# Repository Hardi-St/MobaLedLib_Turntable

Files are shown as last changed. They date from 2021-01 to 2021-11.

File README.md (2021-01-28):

# MobaLedLib
## Turntable Control

### This repository contains the software and the hardware files for a Arduino based turntable control

**Features:**
- Uses a stepper motor for exact positioning
- Manual control using a poti
- Automatic control per rotation switch
- Control by command program using DCC, Selectrix or CAN
- OLED Display
- Sound generation
- Polarisation relais
- ...

**Attention:** This is the first version. Not all features are finished yet

Details could be found here:
https://stummiforum.de/viewtopic.php?t=188668

Contact: MobaLedLib@gmx.de

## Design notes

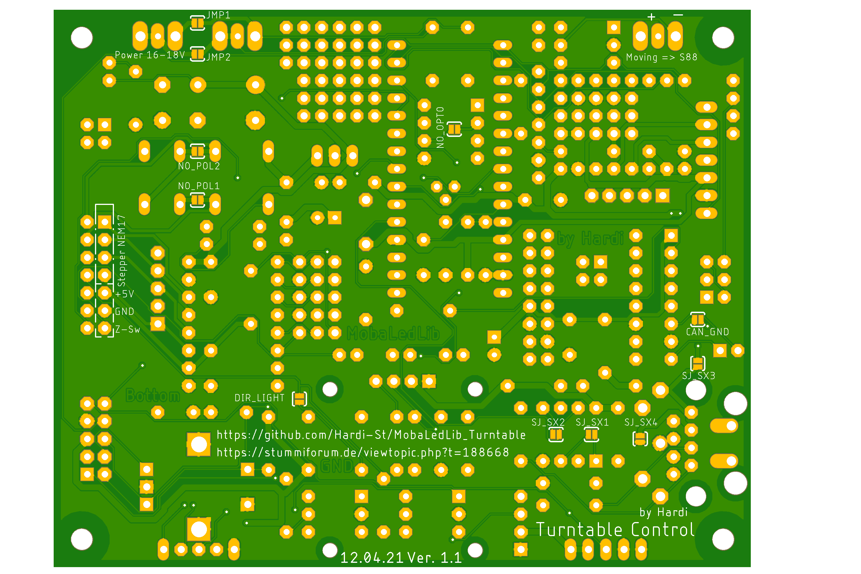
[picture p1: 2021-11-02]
brd/Turntable_Bot.png

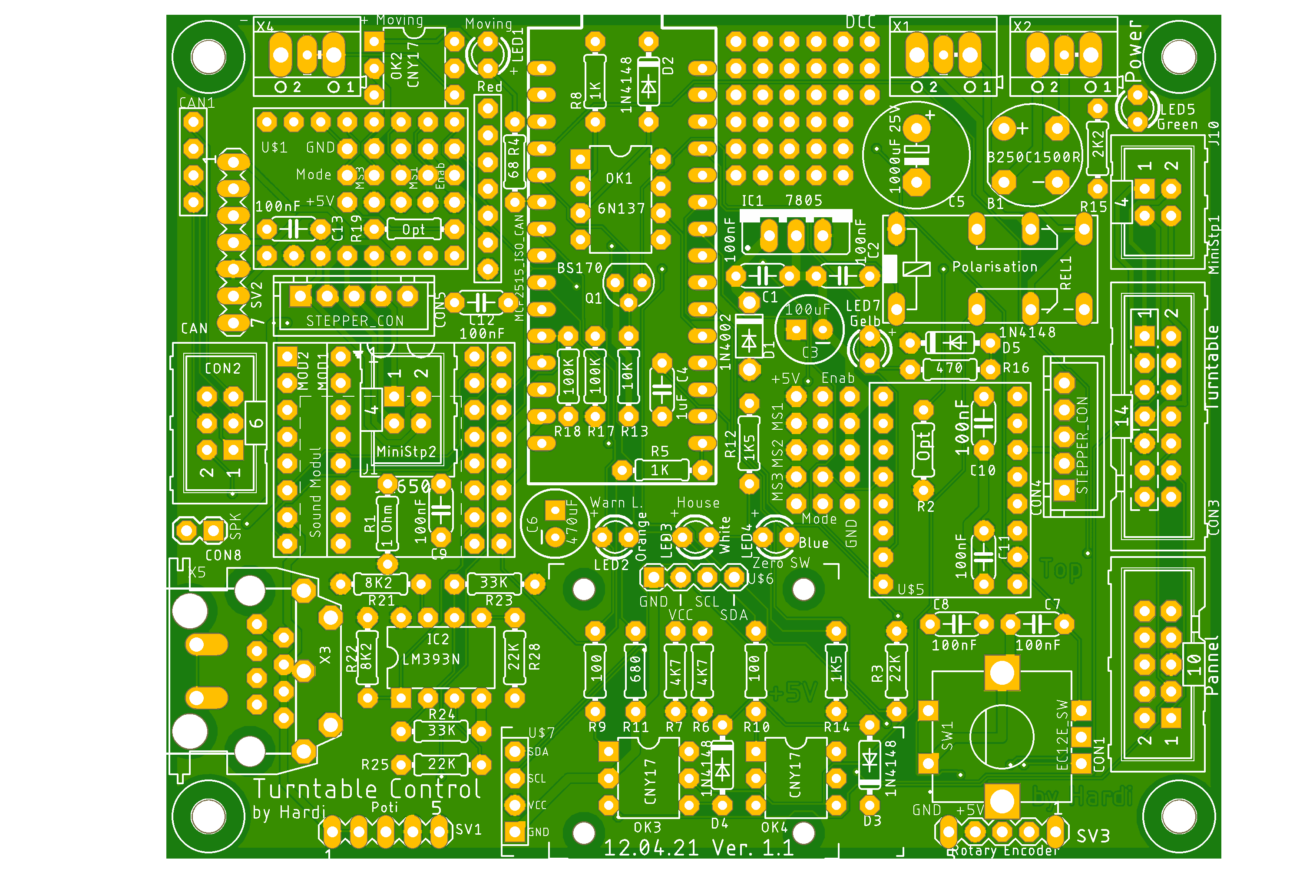
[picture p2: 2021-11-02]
brd/Turntable_Top.png

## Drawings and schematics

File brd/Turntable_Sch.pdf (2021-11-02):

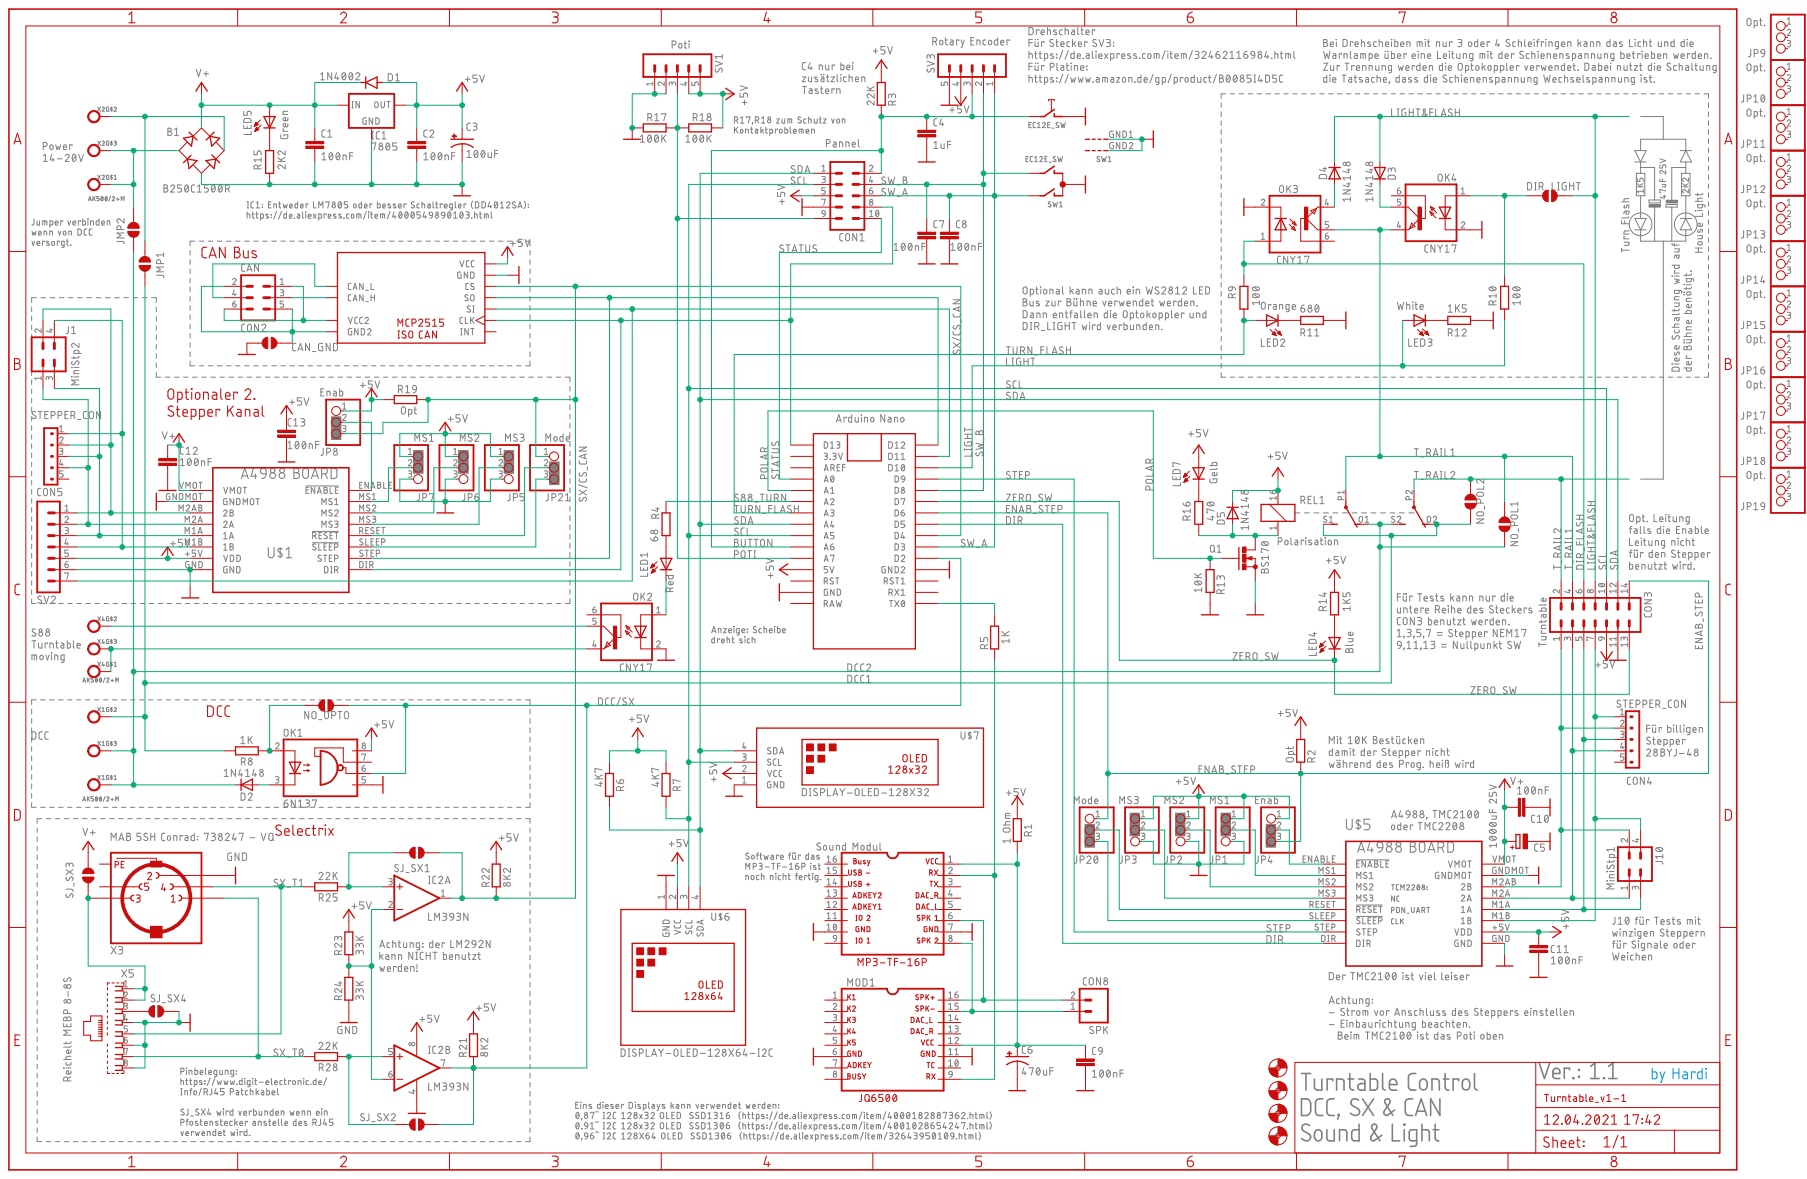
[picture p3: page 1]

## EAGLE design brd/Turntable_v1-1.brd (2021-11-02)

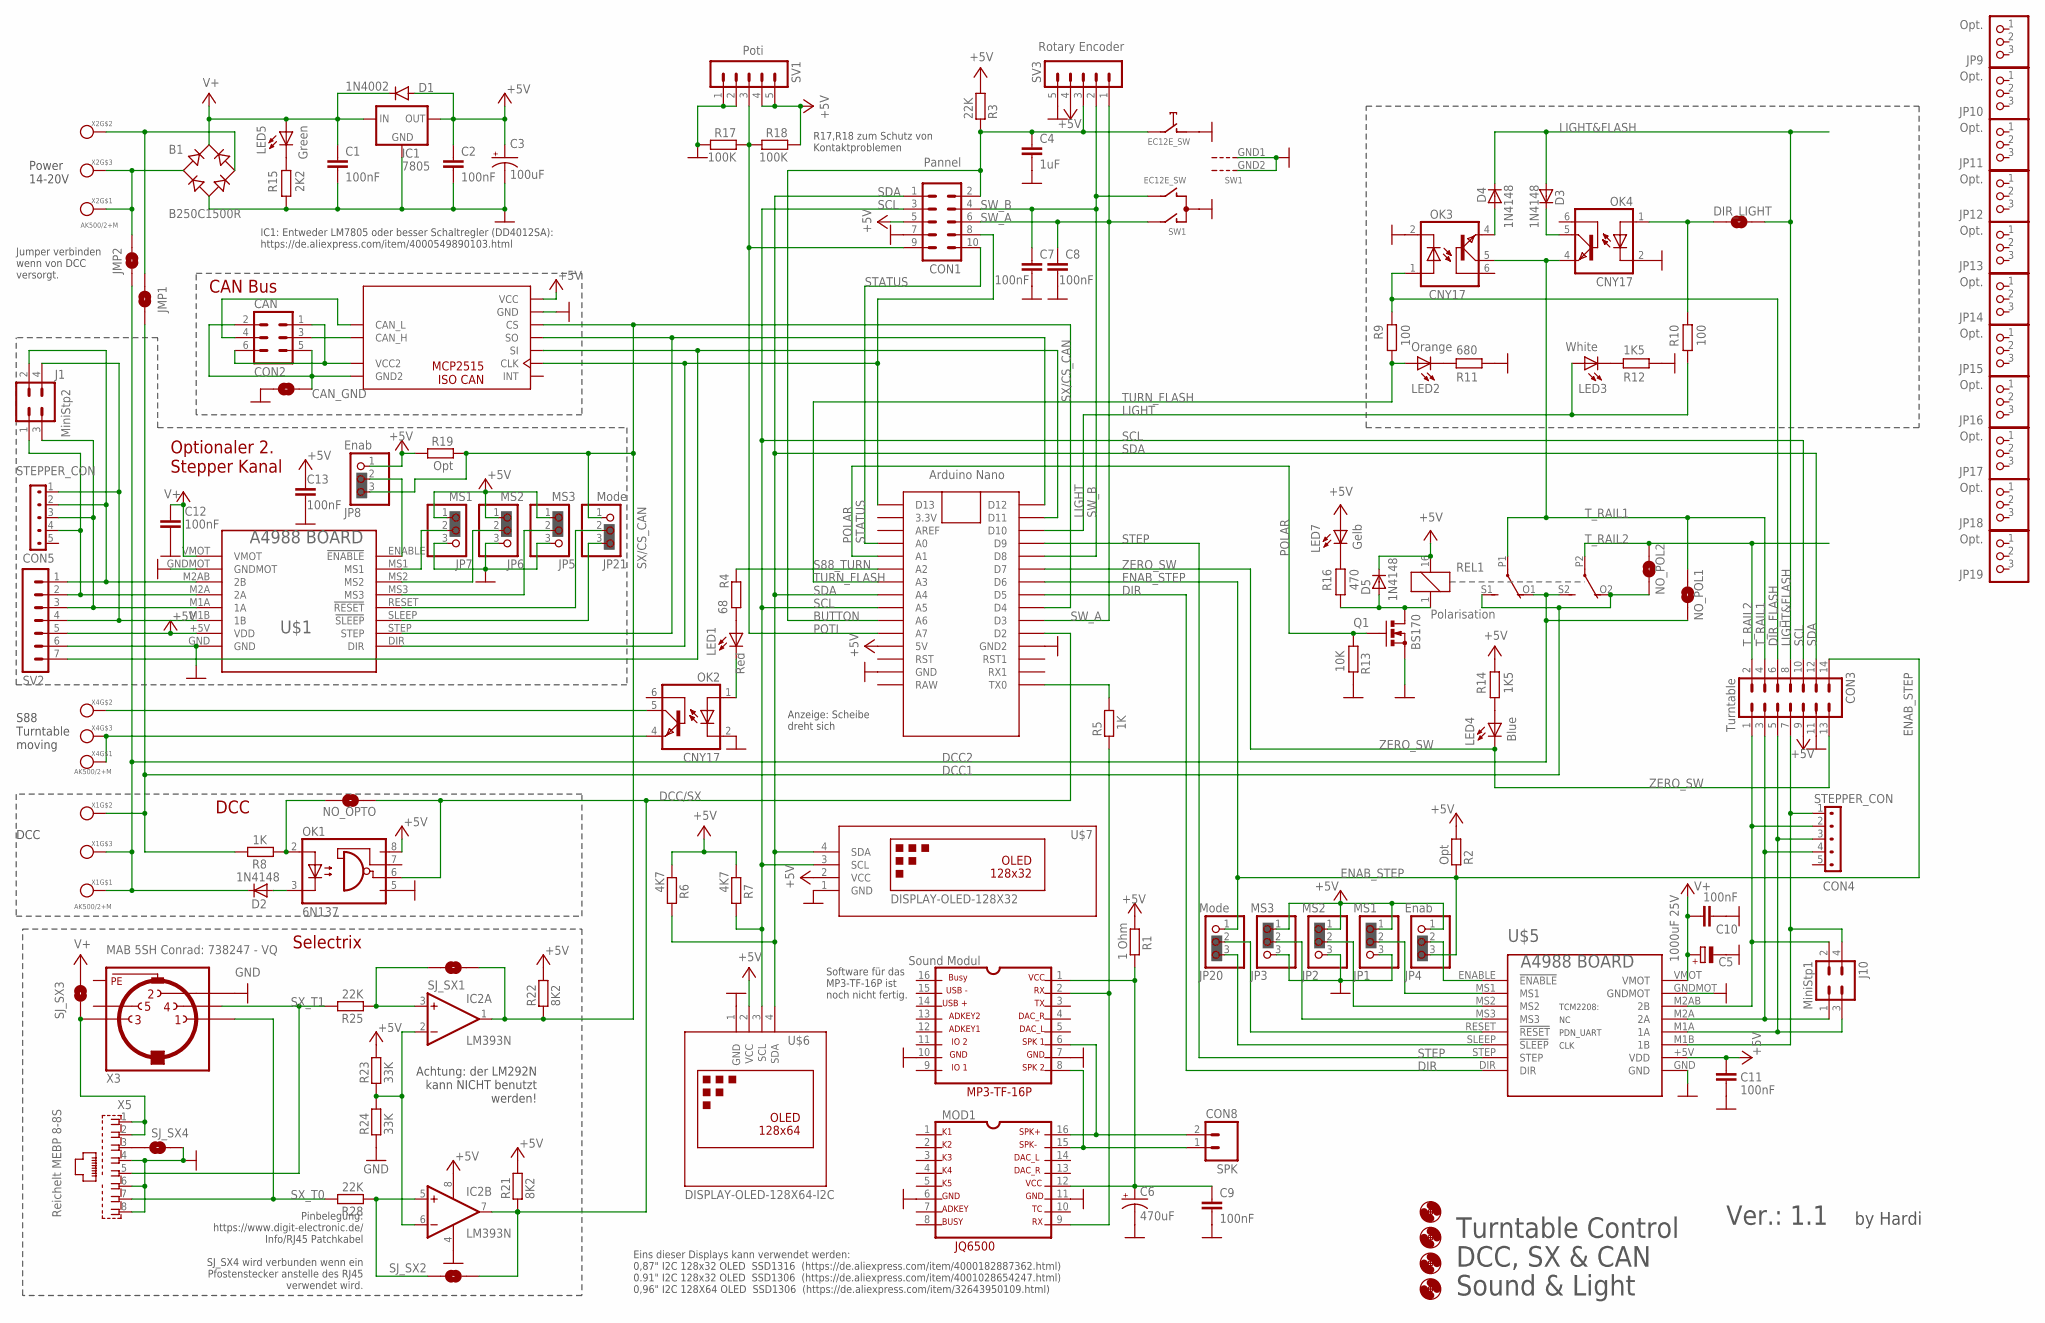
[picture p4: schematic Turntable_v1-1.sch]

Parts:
B1: B250C1500R; RB1A
C1, C2, C7, C8, C9, C10, C11, C12, C13: 100nF; C050-024X044
C3: 100uF; SPARKFUN-CAPACITORS_CPOL-RADIAL-100UF-25V
C4: 1uF; C050-024X044
C5: 1000uF 25V; E5-10,5
C6: 470uF; SPARKFUN-CAPACITORS_CPOL-RADIAL-100UF-25V
CAN1: MCP2515_ISO_CAN
CAN_GND: SOLDERJUMPERNO; SJ_2S-NO
CON1: Pannel; ML10
CON2: CAN; ML6
CON3: Turntable; ML14
CON4, CON5: STEPPER_CON
CON8: SPK; 1X02
D1: 1N4002; DO41-10
D2, D3, D4, D5: 1N4148; DO35-7
DIR_LIGHT: SOLDERJUMPERNO; SJ_2S-NO
H1, H2, H3, H4: MOUNT-HOLE3.0; 3,0
IC1: 7805; 78XXS
IC2: LM393N; DIL08
J1: MiniStp2; CON-HARTING-ML_ML4
J10: MiniStp1; CON-HARTING-ML_ML4
JMP1, JMP2: SOLDERJUMPERNO; SJ_2S-NO
JP1, JP7: MS1; 1X03-CLEANBIG
JP2, JP6: MS2; 1X03-CLEANBIG
JP3, JP5: MS3; 1X03-CLEANBIG
JP4, JP8: Enab; 1X03-CLEANBIG
JP9, JP10, JP11, JP12, JP13, JP14, JP15, JP16, JP17, JP18, JP19: Opt.; 1X03-CLEANBIG
JP20, JP21: Mode; 1X03-CLEANBIG
LED1: Red; LED3MM
LED2: Orange; LED3MM
LED3: White; LED3MM
LED4: Blue; LED3MM
LED5: Green; LED3MM
LED7: Gelb; LED3MM
MOD1: JQ6500
MOD2: Sound Modul; MP3-TF-16P_MP3-TF-16P
NO_OPTO: SOLDERJUMPERNO; SJ_2S-NO
NO_POL1, NO_POL2: SOLDERJUMPERNO; SJ_2S-NO
OK1: 6N137; DIL08
OK2, OK3, OK4: CNY17; DIL06
Q1: BS170; SOT54E
R1: 1 Ohm; RCL_0204/7
R2, R19: Opt; 0204/7
R3, R25, R28: 22K; 0204/7
R4: 68; 0204/7
R5, R8: 1K; 0204/7
R6, R7: 4K7; RCL_0204/7
R9, R10: 100; 0204/7
R11: 680; 0204/7
R12, R14: 1K5; 0204/7
R13: 10K; 0204/7
R15: 2K2; 0204/7
R16: 470; 0204/7
R17, R18: 100K; 0204/7
R21, R22: 8K2; 0204/7
R23, R24: 33K; 0204/7
REL1: Polarisation; 351
SJ_SX1, SJ_SX2, SJ_SX3, SJ_SX4: SOLDERJUMPERNO; SJ_2S-NO
SV1: Poti; MA05-1
SV2: MA07-1
SV3: Rotary Encoder; MA05-1_SMALL_PAD
SW1: EC12E_SW; ALPS_EC12E_SW
U2: LED NANO; NANO
U$1, U$5: BOARD_A4988
U$6: DISPLAY-OLED-128X64-I2C
U$7: DISPLAY-OLED-128X32
X1, X2, X4: AK500/2+M
X3: MAB 5SH Conrad: 738247 - VQ; MAB5SH
X5: Reichelt MEBP 8-8S; RJ45_MEBP8-8S

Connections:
+5V: C2.1, C3.1 (+), C11.1, C13.1, CAN1.1 (VCC), CON1.5, CON3.9, D1.A, D5.C, IC1.OUT, IC2.8 (V+), JP1.1, JP2.1, JP3.1, JP4.1, JP5.1, JP6.1, JP7.1, JP8.1, LED7.A, OK1.8 (VCC), R1.1, R2.2, R3.2, R6.1, R7.1, R14.1, R18.1, R19.2, R21.2, R22.2, R23.2, REL1.16 (2), SV1.4, SV1.5, SV2.5, SV3.4, U2.5V, U$1.+5V (VDD), U$5.+5V (VDD), U$6.2 (VCC), U$7.2 (VCC)
BUTTON: C4.1, CON1.2, R3.1, SV3.3, SW1.E (2), U2.A6
CAN_H: CAN1.9 (CAN_H), CON2.3
CAN_L: CAN1.8 (CAN_L), CON2.4
D11: CAN1.5 (SI), SV2.7, U2.D11
D12: CAN1.4 (SO), U2.D12, U$1.STEP
DCC1: JMP1.2, NO_POL2.2, R8.2, REL1.O2 (O), REL1.S1 (S), X1.2
DCC2: D2.C, JMP2.2, NO_POL1.2, REL1.O1 (O), REL1.S2 (S), X1.1, X1.M
DCC/SX: IC2.7 (OUT), NO_OPTO.1, OK1.6 (VO), R21.1, SJ_SX2.2, U2.D2
DIR: U2.D5, U$5.DIR
DIR_FLASH: CON3.6, OK3.1 (A), R9.1
ENAB_STEP: CON3.14, JP4.3, JP20.1, R2.1, U2.D6
GND: B1.-, C1.2, C2.2, C3.2 (-), C4.2, C5.-, C6.2 (-), C7.2, C8.2, C9.2, C10.2, C11.2, C12.2, C13.2, CAN1.2 (GND), CAN_GND.2, CON1.7, CON3.11, IC1.GND, IC2.4 (V-), JP1.3, JP2.3, JP3.3, JP5.3, JP6.3, JP7.3, MOD1.6, MOD1.11, MOD2.7, MOD2.10, OK1.5 (GND), OK2.2 (C), OK3.2 (C), OK4.2 (C), Q1.S, R11.2, R12.2, R13.2, R15.2, R17.2, R24.1, SJ_SX4.2, SV1.1, SV1.2, SV2.6, SV3.5, SW1.C, SW1.D (1), SW1.GND1 (G), SW1.GND2 (G), U2.GND, U2.GND1 (GND2), U$1.GND, U$1.GNDMOT, U$5.GND, U$5.GNDMOT, U$6.1 (GND), U$7.1 (GND), X3.2, X5.4, X5.6, X5.8
LIGHT: LED3.A, R10.2, U2.D10
LIGHT&FLASH: CON3.8, D3.A, D4.C, DIR_LIGHT.2
unnamed: JP5.2, U$1.MS3
unnamed: SJ_SX4.1, X5.3
unnamed: CAN1.11 (GND2), CAN_GND.1, CON2.2, CON2.5
unnamed: C6.1 (+), C9.1, MOD1.12, MOD2.1, R1.2
unnamed: CAN1.6 (CLK), CON1.8, U2.D13, U$1.DIR
unnamed: CON8.1, MOD1.15, MOD2.8
unnamed: MOD1.9, MOD2.2, R5.1
unnamed: LED1.K (C), OK2.1 (A)
unnamed: CON8.2, MOD1.16, MOD2.6
unnamed: CAN1.10 (VCC2), CON2.1, CON2.6
unnamed: R5.2, U2.TX0
unnamed: B1.AC2, JMP1.1, X2.2
unnamed: B1.AC1, JMP2.1, X2.1, X2.M
unnamed: JP2.2, U$5.MS2
unnamed: D2.A, OK1.3 (C)
unnamed: LED2.K (C), R11.1
unnamed: D5.A, Q1.D, R16.2, REL1.1
unnamed: LED1.A, R4.1
unnamed: OK2.4 (EMI), X4.1, X4.M
unnamed: OK2.5 (COL), X4.2
unnamed: NO_OPTO.2, OK1.2 (A), R8.1
unnamed: JP1.2, U$5.MS1
unnamed: LED3.K (C), R12.1
unnamed: LED4.A, R14.2
unnamed: JP4.2, U$5.ENABLE (!ENABLE)
unnamed: SJ_SX3.1, X3.3, X5.1, X5.2
unnamed: JP3.2, U$5.MS3
unnamed: D4.A, OK3.4 (EMI)
unnamed: D3.C, OK4.5 (COL)
unnamed: JP20.2, U$5.RESET (!RESET)
unnamed: CON3.1, CON4.2, J10.2, U$5.M2AB (2B)
unnamed: JP21.3, U$1.SLEEP (!SLEEP)
unnamed: JP20.3, U$5.SLEEP (!SLEEP)
unnamed: LED5.K (C), R15.1
unnamed: CON3.7, CON4.1, J10.4, U$5.M1B (1B)
unnamed: LED7.K (C), R16.1
unnamed: DIR_LIGHT.1, OK4.1 (A), R10.1
unnamed: IC2.2 (-IN), IC2.6 (-IN), R23.1, R24.2
unnamed: IC2.3 (+IN), R25.1, SJ_SX1.1
unnamed: CON3.3, CON4.4, J10.1, U$5.M2A (2A)
unnamed: CON3.5, CON4.3, J10.3, U$5.M1A (1A)
unnamed: IC2.5 (+IN), R28.1, SJ_SX2.1
unnamed: JP6.2, U$1.MS2
unnamed: JP7.2, U$1.MS1
unnamed: JP8.2, U$1.ENABLE (!ENABLE)
unnamed: JP21.2, U$1.RESET (!RESET)
unnamed: CON5.2, J1.2, SV2.1, U$1.M2AB (2B)
unnamed: CON5.4, J1.1, SV2.2, U$1.M2A (2A)
unnamed: CON5.3, J1.3, SV2.3, U$1.M1A (1A)
unnamed: CON5.1, J1.4, SV2.4, U$1.M1B (1B)
PE: X3.PE, X3.PE@ (PE)
POLAR: Q1.G, R13.1, U2.A1
POTI: CON1.9, R17.1, R18.2, SV1.3, U2.A7
S88_TURN: R4.2, U2.A2
SCL: CON1.3, CON3.10, R7.2, U2.A5, U$6.3 (SCL), U$7.3 (SCL)
SDA: CON1.1, CON3.12, R6.2, U2.A4, U$6.4 (SDA), U$7.4 (SDA)
STATUS: CON1.10, U2.A0
STEP: U2.D9, U$5.STEP
SW_A: C8.1, CON1.6, SV3.1, SW1.A, U2.D3
SW_B: C7.1, CON1.4, SV3.2, SW1.B, U2.D8
SX/CS_CAN: CAN1.3 (CS), IC2.1 (OUT), JP8.3, JP21.1, R19.1, R22.1, SJ_SX1.2, U2.D4
SX_T0: R28.2, X3.1, X5.7
SX_T1: R25.2, X3.4, X5.5
TURN_FLASH: LED2.A, R9.2, U2.A3
T_RAIL1: CON3.4, NO_POL1.1, OK3.5 (COL), OK4.4 (EMI), REL1.P1
T_RAIL2: CON3.2, NO_POL2.1, REL1.P2
V+: B1.+, C1.1, C5.+, C10.1, C12.1, D1.C, IC1.IN, LED5.A, SJ_SX3.2, U$1.VMOT, U$5.VMOT
ZERO_SW: CON3.13, LED4.K (C), U2.D7

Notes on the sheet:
Pinbelegung: https://www.digit-electronic.de/ Info/RJ45 Patchkabel SJ_SX4 wird verbunden wenn ein Pfostenstecker anstelle des RJ45 verwendet wird.
Achtung: der LM292N kann NICHT benutzt werden!
DCC
IC1: Entweder LM7805 oder besser Schaltregler (DD4012SA): https://de.aliexpress.com/item/4000549890103.html
by Hardi
Ver.: 1.1
Turntable Control DCC, SX & CAN Sound & Light
S88 Turntable moving
Power 14-20V
R17,R18 zum Schutz von Kontaktproblemen
Optionaler 2. Stepper Kanal
Jumper verbinden wenn von DCC versorgt.
Anzeige: Scheibe dreht sich
Software für das MP3-TF-16P ist noch nicht fertig.
DCC
CAN Bus
Selectrix
Eins dieser Displays kann verwendet werden: 0,87" I2C 128x32 OLED SSD1316 (https://de.aliexpress.com/item/4000182887362.html) 0.91" I2C 128x32 OLED SSD1306 (https://de.aliexpress.com/item/4001028654247.html) 0,96" I2C 128X64 OLED SSD1306 (https://de.aliexpress.com/item/32643950109.html)
TCM2208: NC PDN_UART CLK

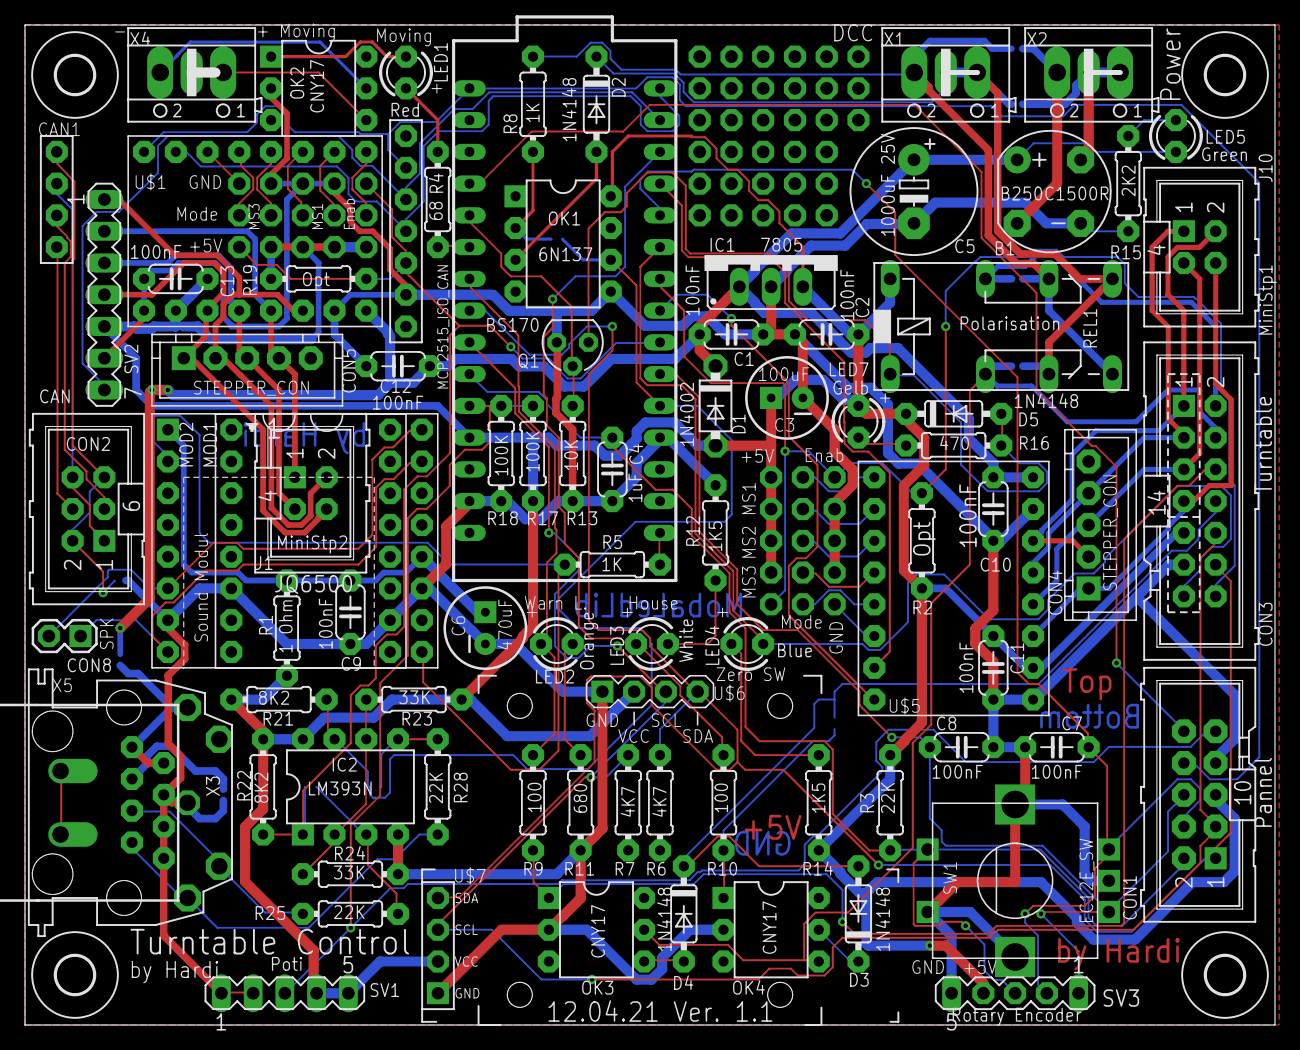
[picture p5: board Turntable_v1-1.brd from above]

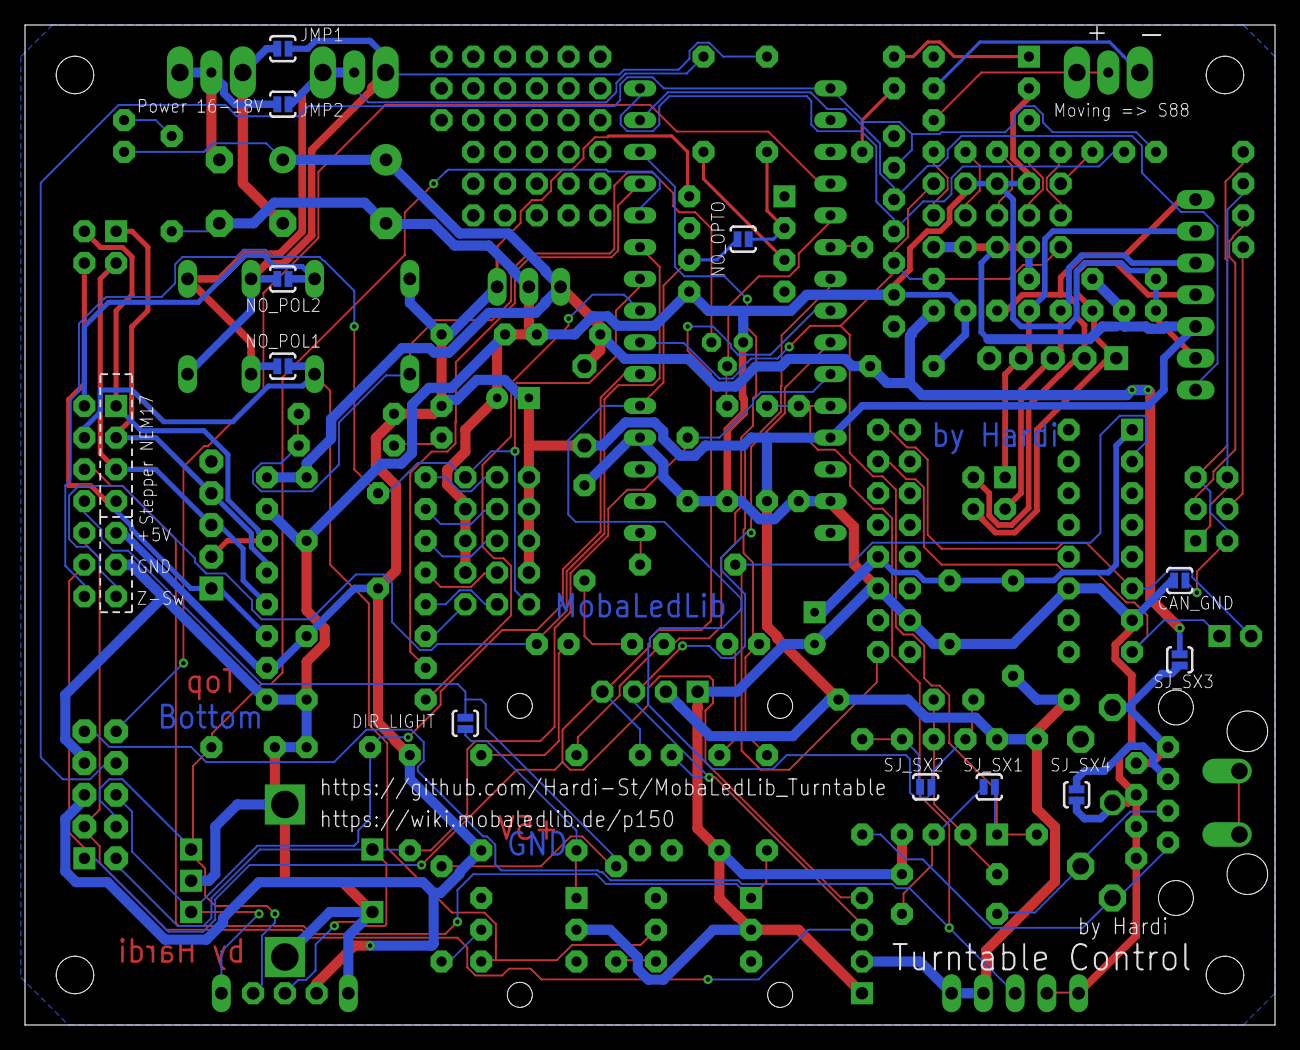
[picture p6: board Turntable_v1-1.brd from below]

Board: 2 copper layers, 100.0 x 80.0 mm, 119 parts (11 on the bottom side), 83 nets.

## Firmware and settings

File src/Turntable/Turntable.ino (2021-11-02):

/*
 The idea to create a own inexpensive hard and software for a turntable was generated by this post from Frank:
   https://www.stummiforum.de/viewtopic.php?t=140471&start=401&sd=a

 He uses the 3D printed turntabele from
   https://www.thingiverse.com/thing:1837520
31083 30916 167

 Revision History:
 ~~~~~~~~~~~~~~~~~
 13.12.20:  - Setting zero position if more than one turn is detected in both directions
            - Fast move to contact point with poti
 15.12.20:  - Current for stepper (28BYJ-48) incremented 0.17V = 300mA to prevent
              loosing steps (Old: 0.14V = 200mA)
 21.12.20:  - Actual Current settings 0.24V (Changed back to 0.14 later because the stepper gets to hot)
 26.12.20:  - Reading the actual port from the step position if moved by poti
            - Using a quadratic function to define the speed for a finer positioning
            - Reading the Port_Pos[] directly from the EEPROM to save RAM
            - Use FastPin instead of digitalWrite function to save memory and speed op the program
 27.12.20:  - Added the rotation switch menu
 28.12.20:  - Saving the position to the EEPROM to avoid callibration at startup
            - Port numbers shown to the user start with 1 and not with 0
            - Corrected Get_Next_Port_from_Actual_Position() to be able to use negativ Port_Pos[] entries
            - Detect if the poti is not 0 at the beginning
 29.12.20:  - Added the polarisation relais function
 02.01.21:  - Support for the u8x8 display mode which saves 10% Flash and doesn't need RAM for the display buffer
            - Option to use a second lagrer font for the numbers
 03.01.21:  - Reset uses the Jump 0 command because the watchdog reset doesn't work when an old bootloader is used
            - Polarisation relais could be configured individuel for each port
 05.01.21:  - Added several functions to controll the turntable with DCC
            - Prevent overwriting the EEPROM by the NmraDcc library
            - Support for 0.96" OLED display with 128x64 pixel
            - Pin which indicates that the turntable is moving to conect a S88 modul.
 07.01.21:  - Added the ability to change the rotation / port number direction of the turntable "TURNTABLE_DIRECTION"
            - Port number could be selected in the "Save position" menu only once at the beginning to
              prevent wrong sequences. Call "Reset all" to change the sequence.
            - Moved the poti to A7 because A0 could also be used as output. This could be changed with:
                #define POTI_PIN A0
            - Moved the rotation switch button to A6. This could be changed with:
                #define ENCODER_SW_PIN 9
              to the old pin number in the config file
            - Light which flashes while the turntable moves
            - Added the "avdweb_AnalogReadFast.h library to read speed up the analog reading
            - Diagnose display to check the analog values
            - Activating a sound modul if the turntable starts/stops moving
            - Additional DCC functions for Sound and Light
 08.01.21:  - Last menu position is stored. By default the "Reverse" line is activated
              => A double click could be used to reverse the turntable.
              This is also useful to save the port positions...
            - Stopping fast if the poti is turned to 0. Prior the time depends on the last speed.
            - Added MOVING_FLASH_INVERS
            - Filling also the port positions of the oposite direction with standard values when the first
              port in oposite direction is defined
 09.01.21:  - Storing Act_Port to the EEPROM
            - New handling of the reverse command. The start port is stored to Rev_Port to be able to
              rotate back again. The display shoa the reverse port in a second line.
            - Soved problem with Port < 24 at two positions
              - caused the wrong turn direction at Port 0 when tuned the rotation key back to 24
              - storing the Act_Port in Reverse_TurnTable
            - Checked with the maximal PORT_CNT of 80.
            - Corrected Get_Next_Port_from_Actual_Position(). Problem if one port is left, the other right of 0
            - Zero position is always set in positive direction
              Could be disabled with #define ALWAYS_SET_ZERO_IN_POS_DIR  0
              Prior it was only set after one turn.
            - Reversing the turntable if the same port command is received twice.
              Could be disabeld with #define REVERSE_IF_SAME_PORT_IS_RECEIVED 0
              If it's disabled the sound is not played.
 10.01.21:  - Storing the reverse positions to the EEPROM to be able to adjust them individually
            - Replaced the "Move_to_Port_or_Pos()" Function by two separate functions:
              "Move_to_Port()" and "Move_to_StepPos()" because the old function used the value of the parameter
              to detect if it was ment as Port or StepPos (Abs(x) < 2*PORT_CNT). This was fine for manual
              tests, but can't be used in an automatic mode where a StepPos could also be < PORT_CNT.
 11.01.21:  - Disabled the flickering of the display if USE_u8x8 is used
            - New menu option "Move manual"
            - Improved the decoding of the rotation switch
            - Corrected playing sound at the beginning of the movement
 12.01.21:  - Using the serial port to play the sounds
              - Number of sounds could be lager. At the moment 8 files could be used with DCC
              - Is connected to the serial port => No other pin needed
              - Debug outputs must use 9600 Baud ;-( but debuging is still possible in paralel
              - DCC Functions added to change the volume
            - Don't reverse per DCC while moving
 17.01.21:  => Send to Han
            - Moving to contact before moving to a port. This caused a lot of changes.
            - Delayed start moving if DELAY_TURN_START_SOUND is given
 23.01.21:  - Added Menu Sound
 10.02.21:  - Added 1.3" OLED Display
            - I2C speed set tor 400kHz
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

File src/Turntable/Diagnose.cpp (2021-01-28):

/*
 Diagnose functions for the turntable
 ~~~~~~~~~~~~~~~~~~~~~~~~~~~~~~~~~~~~
 - Check lost stepps
   - At constant speed
   - When acceleration deceleration is used
*/

#include <Arduino.h>
#include <MobaTools.h>  // https://github.com/MicroBahner/MobaTools

#include "Turntable_Config.h"       // Local configuration file. The file could be empty. In this case the default values are used (See below).
#include "Diagnose.h"

#ifndef ENABLE_DIAGNOSE
#define ENABLE_DIAGNOSE              0
#endif

#ifndef DIAG_CONST_SPEED_START_SPEED
#define DIAG_CONST_SPEED_START_SPEED 25000
#endif

#ifndef DIAG_CONST_SPEED_END_SPEED
#define DIAG_CONST_SPEED_END_SPEED   10000
#endif

#ifndef DIAG_CONST_SPEED_SPEED_STEPP
#define DIAG_CONST_SPEED_SPEED_STEPP -1000
#endif

#ifndef DIAG_CONST_SPEED_N_TESTS
#define DIAG_CONST_SPEED_N_TESTS     5
#endif

//#ifndef DIAG_PAUSE_BETWEEN_TESTS
//#define DIAG_PAUSE_BETWEEN_TESTS     0   // [s]
//#endif

#ifndef DIAG_START_OFFSET
#define DIAG_START_OFFSET            3000
#endif





extern class MoToStepper Step1;

bool Get_Zero_SW();
void WaitforZeroSwitch(bool val);
long WaitforZeroSwitch_readSteps_Debounce(bool val);
void WaitforZeroSwitch_and_SetZero();
void WaitUntilStopped(bool DisableA4988);

//----------------------------------------------
long Check_Steps_for_one_Turn(uint16_t CalSpeed)
//----------------------------------------------
{
  long StepsOneTurn;
  Step1.rotate(1);
  Step1.setSpeedSteps(CalSpeed);

  if (Get_Zero_SW())                          // If the zero switch is achtive => Move until it's released
     WaitforZeroSwitch_readSteps_Debounce(0); // Wait until the zero switch is released

  // *** Set the zero position ***
  //DprintlnT("Searching the zero position...");
  WaitforZeroSwitch_and_SetZero();

  // *** Get the total number of steps ***
  WaitforZeroSwitch_readSteps_Debounce(1);    // Debouncing
  WaitforZeroSwitch_readSteps_Debounce(0);    // Wait until the switch is 0
  //DprintlnT("Rotate one turn to get the total number of steps");

  WaitforZeroSwitch(1);                       // Rotate one turn until the switch is active again
  StepsOneTurn = Step1.readSteps();
  Step1.setZero();
  Serial.print(F("Speed: ")); Serial.print(CalSpeed); Serial.print(F(" StepsOneTurn: ")); Serial.println(StepsOneTurn);
  Step1.doSteps((long)-DIAG_START_OFFSET); // Move back (To start at the same position)
  WaitUntilStopped(false);
  return StepsOneTurn;
}

//-----------------------------------------------------------------
void Check_Steps_for_one_Turn_N_times(uint16_t CalSpeed, uint8_t n)
//-----------------------------------------------------------------
{
 long StepsOneTurn_Sum = 0;
 long MaxVal = 0;
 long MinVal = 0x7FFFFFFF;
 for (uint8_t i = 0; i < n; i++)
    {
    long StepsOneTurn = Check_Steps_for_one_Turn(CalSpeed);
    StepsOneTurn_Sum += StepsOneTurn;
    if (StepsOneTurn > MaxVal) MaxVal = StepsOneTurn;
    if (StepsOneTurn < MinVal) MinVal = StepsOneTurn;
    }
 Serial.print(F(". . . .\t\t\t\t\t\t\tAvg: ")); Serial.print(StepsOneTurn_Sum/n); Serial.print(F(" MaxDif: ")); Serial.println(MaxVal - MinVal);
}

//----------------------------------
void Check_Steps_at_Constant_Speed()
//----------------------------------
// Check the number of steps for one turn at different but constant speeds
{
  uint16_t CalSpeed = DIAG_CONST_SPEED_START_SPEED;
  do {
     Check_Steps_for_one_Turn_N_times(CalSpeed, DIAG_CONST_SPEED_N_TESTS);
     CalSpeed += DIAG_CONST_SPEED_SPEED_STEPP;
     } while((DIAG_CONST_SPEED_SPEED_STEPP > 0 && CalSpeed <= DIAG_CONST_SPEED_END_SPEED) ||
             (DIAG_CONST_SPEED_SPEED_STEPP < 0 && CalSpeed >= DIAG_CONST_SPEED_END_SPEED));
}
/*

Lego "Stepper" ohne Getriebe und ohne Reibung, A4988, MS1-3 +5v, 0.2A, 0.152V, 14V, A4988
Speed: 5000 StepsOneTurn: 32752
Speed: 5000 StepsOneTurn: 32762
Speed: 5000 StepsOneTurn: 32764
Speed: 5000 StepsOneTurn: 32771
Speed: 5000 StepsOneTurn: 32769
. . . .                         Avg: 32763 MaxDif: 19
Speed: 6000 StepsOneTurn: 32767
Speed: 6000 StepsOneTurn: 32763
Speed: 6000 StepsOneTurn: 32768
Speed: 6000 StepsOneTurn: 32769
Speed: 6000 StepsOneTurn: 32768
. . . .                         Avg: 32767 MaxDif: 6
Speed: 7000 StepsOneTurn: 32765
Speed: 7000 StepsOneTurn: 32769
Speed: 7000 StepsOneTurn: 32786
Speed: 7000 StepsOneTurn: 32768
Speed: 7000 StepsOneTurn: 32769
. . . .                         Avg: 32771 MaxDif: 21
Speed: 8000 StepsOneTurn: 32767
Speed: 8000 StepsOneTurn: 32768
Speed: 8000 StepsOneTurn: 32767
Speed: 8000 StepsOneTurn: 32766
Speed: 8000 StepsOneTurn: 32768
. . . .                         Avg: 32767 MaxDif: 2
Speed: 9000 StepsOneTurn: 32765
Speed: 9000 StepsOneTurn: 32768
Speed: 9000 StepsOneTurn: 32768
Stepper war am Ende so Heiß, dass man sich die Finger verbrennt wenn man ihn lönger als 2 Sek. berührt


Großer Stepper mit Lego ohne Getriebe und ohne Reibung, A4988, MS1-3 +5v, 0.2A, 0.152V, 14V, A4988

Speed: 5000 StepsOneTurn: 3200
Speed: 5000 StepsOneTurn: 3200
Speed: 5000 StepsOneTurn: 3200
Speed: 5000 StepsOneTurn: 3200
Speed: 5000 StepsOneTurn: 3200
. . . .                         Avg: 3200 MaxDif: 0
Speed: 6000 StepsOneTurn: 3200
Speed: 6000 StepsOneTurn: 3200
Speed: 6000 StepsOneTurn: 3200
Speed: 6000 StepsOneTurn: 3200
Speed: 6000 StepsOneTurn: 3200
. . . .                         Avg: 3200 MaxDif: 0
Speed: 7000 StepsOneTurn: 3200
Speed: 7000 StepsOneTurn: 3200
Speed: 7000 StepsOneTurn: 3200
Speed: 7000 StepsOneTurn: 3200
Speed: 7000 StepsOneTurn: 3200
. . . .                         Avg: 3200 MaxDif: 0
Speed: 8000 StepsOneTurn: 3200
Speed: 8000 StepsOneTurn: 3200
Speed: 8000 StepsOneTurn: 3200
Speed: 8000 StepsOneTurn: 3200
Speed: 8000 StepsOneTurn: 3200
. . . .                         Avg: 3200 MaxDif: 0
Speed: 9000 StepsOneTurn: 3200
Speed: 9000 StepsOneTurn: 3200
Speed: 9000 StepsOneTurn: 3200
Speed: 9000 StepsOneTurn: 3200
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

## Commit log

2021-01-28 First Version
    [Turntable.brd, Turntable.sch]
2021-01-28 Correchted spelling
    [Turntable.brd, Turntable.sch]
2021-01-31 Corrected Potary Encoder Pins
    [Turntable.brd, Turntable.sch]
2021-02-02 Final Version 1.0
    [Turntable.brd, Turntable.sch]
2021-02-15 Updated LM292 Text
    [Turntable.sch]
2021-04-13 Version 1.1
    + R6 and R7, PullUps for I2C
    ~ CAN-Modul: changed VCC to +5V
    [Turntable_v1-1.brd, Turntable_v1-1.sch]
2021-05-29 Update Link
    [Turntable_v1-1.brd]
2021-11-02 Added 1.3" OLED and Speed Up I2C

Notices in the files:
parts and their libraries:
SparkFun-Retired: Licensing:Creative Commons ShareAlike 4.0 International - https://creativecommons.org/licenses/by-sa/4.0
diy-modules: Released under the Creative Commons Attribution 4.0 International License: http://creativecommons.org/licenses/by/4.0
